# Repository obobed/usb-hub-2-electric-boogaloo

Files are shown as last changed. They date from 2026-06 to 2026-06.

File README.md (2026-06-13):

# UEB2
## another usb hub!
I made this since I wanted a unique USB hub with cool colours unlike some bland and boring ones you find off Amazon or places like that. It has 2 USB-C, 1 USB-A and an Micro SD card slot for downstream ports, and a USB-C female port for the upstream, alongside a cool 3D printed case with cool accent colours and an acrylic top window.

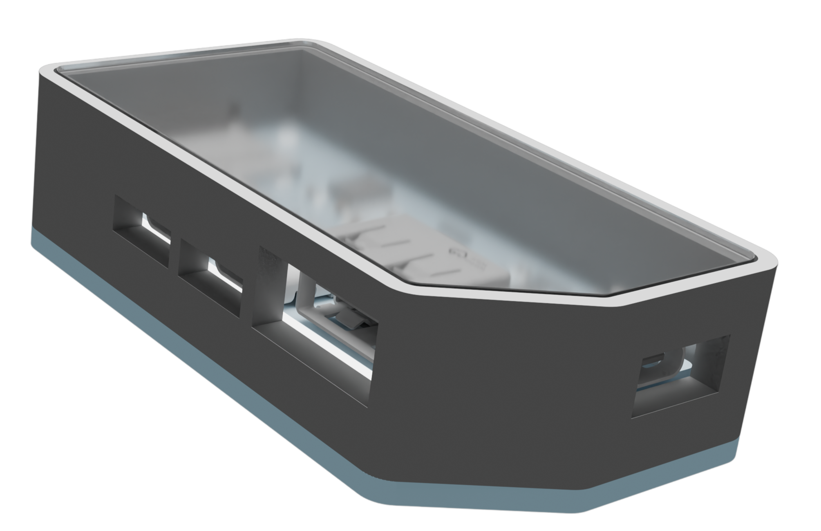
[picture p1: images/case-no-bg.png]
3d render of the case and pcb


## Repo Structure
When a directory includes a folder named "archive", that contains the files I used before I modified my PCB to use a female upstream port instead of a male one
* [/3D](/3D) - 3D models (both the components and the whole pcb exported as a STEP)
* [/cad](/cad) - my case exported from onshape (you can view the actual onshape link below), has both models with the PCB inside, and without the PCB
* [/images](/images) - various image assets used in my readme (here) and my zine!
* [/pcb](/pcb) - all of my kicad design files
* [/plots](/plots) - various plots, including dxfs for each layer, and a schematic image
* [/production](/production) - contains everything needed for PCB production, like gerbers and a component BOM
* [/rendering](/rendering) - the documents I used in Blender to render my design, with the OnShape exported objs in a subfolder
* [/zine](/zine) - my Zine! pdf and png included, and most assets are in [/images](/images)

## CAD
[OnShape link here!](https://cad.onshape.com/documents/3911889ee056a8d8e4ba98bf/w/b6e308ebfed3eeb37e65c26c/e/fc788076bb25bd97f4780c85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)
Step files can be found in [/cad](cad/)

## Images
### Schematic
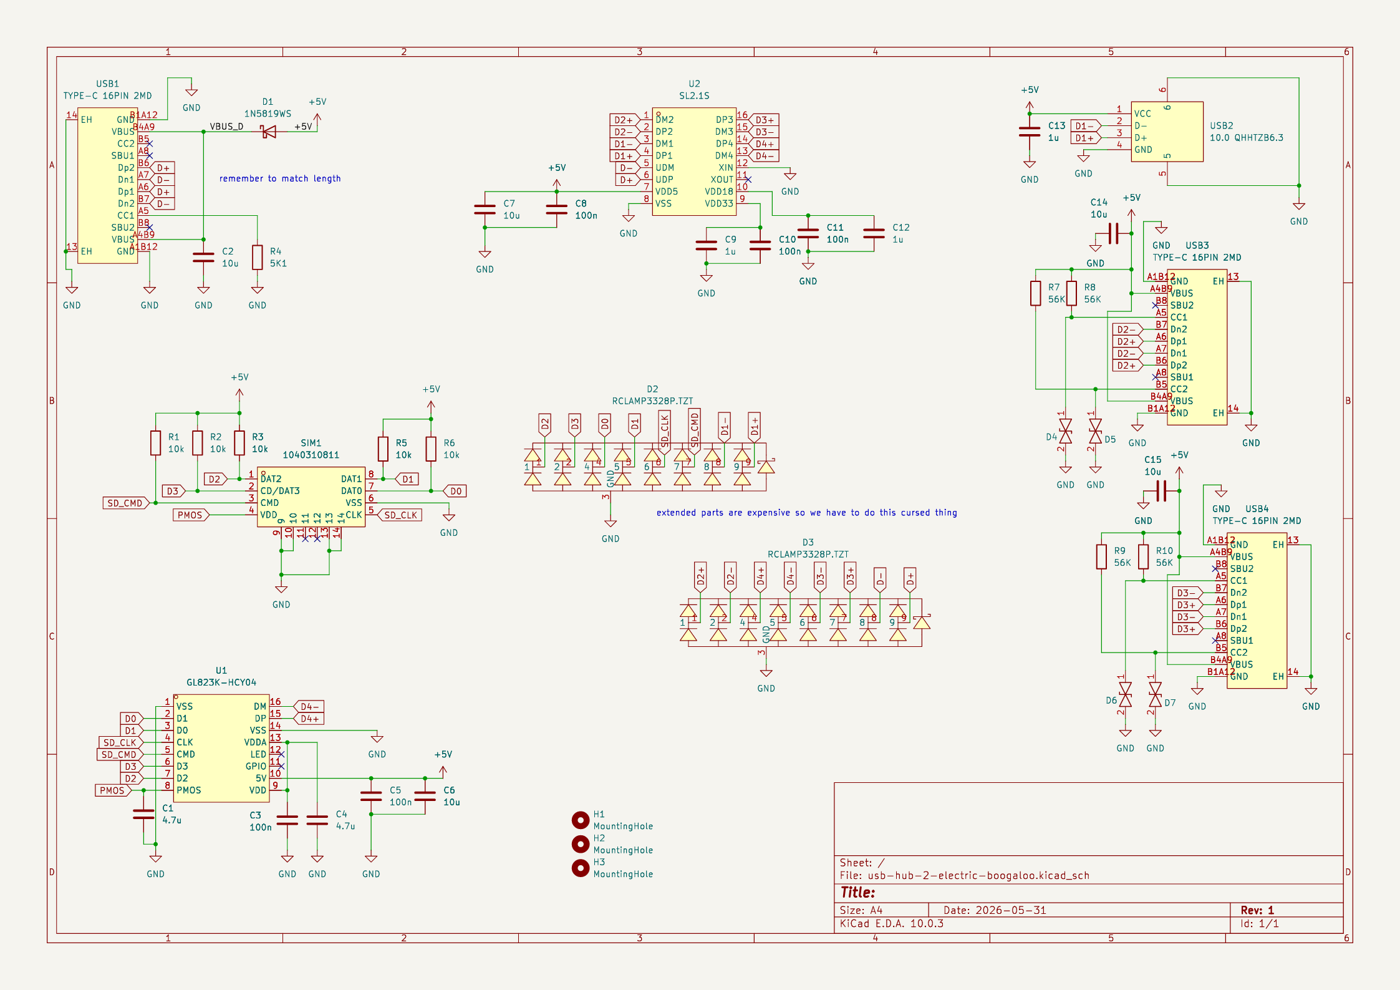
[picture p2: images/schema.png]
schematic


### 3D Model
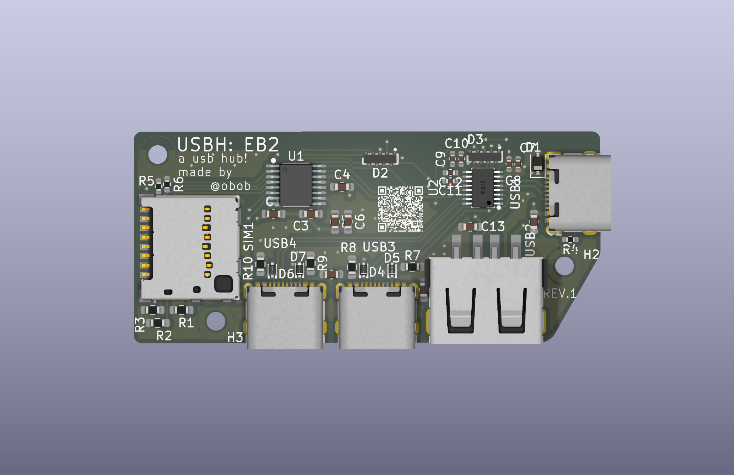
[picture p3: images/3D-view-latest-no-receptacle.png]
3D front view

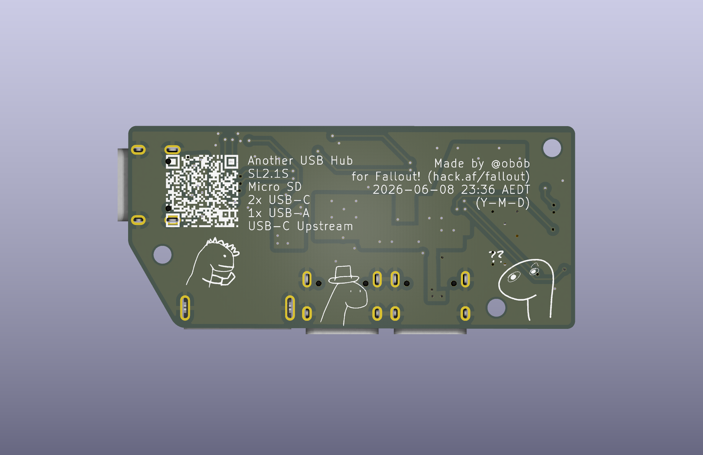
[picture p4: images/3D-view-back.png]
3D back view


### PCB
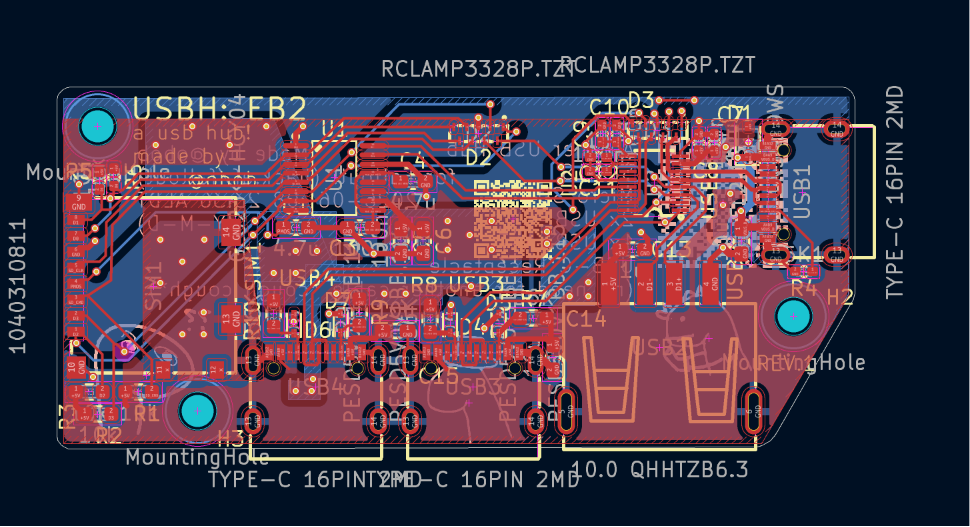
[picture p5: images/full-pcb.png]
full pcb image


#### Front Copper
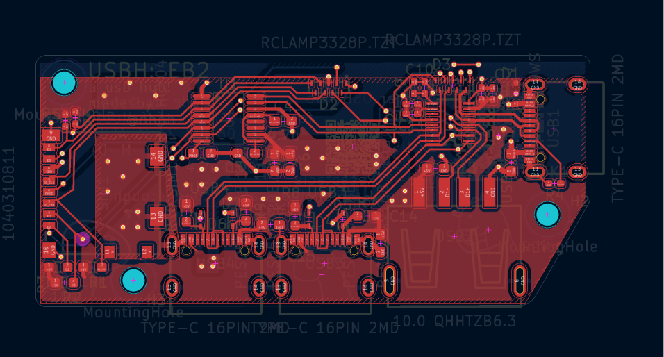
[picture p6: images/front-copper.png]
front copper pcb image


#### Back Copper
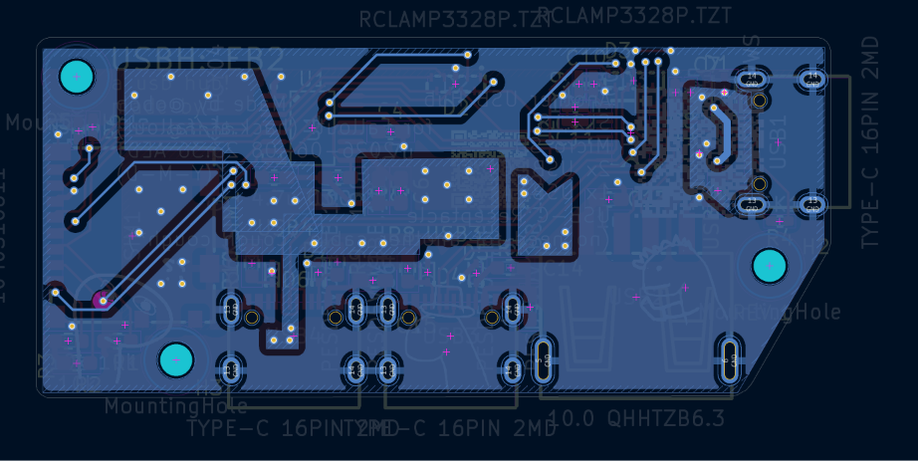
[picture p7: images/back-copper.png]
back copper pcb image


#### Silkscreen
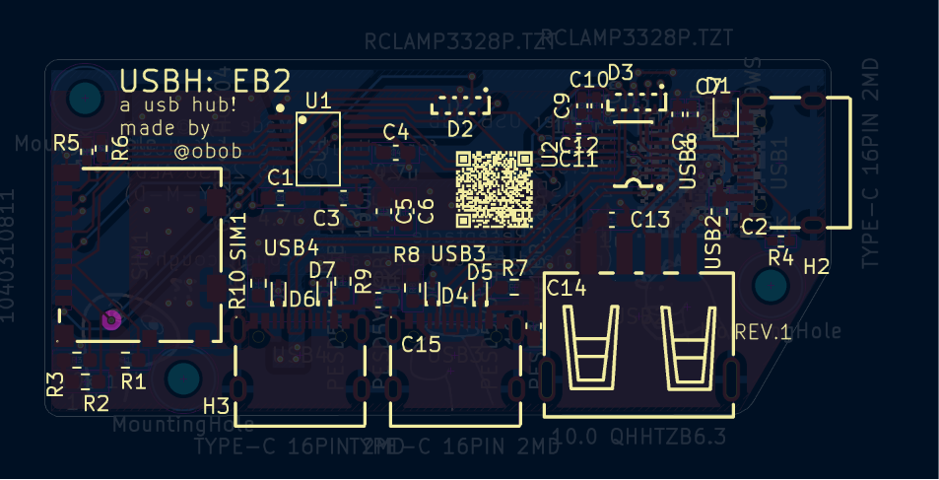
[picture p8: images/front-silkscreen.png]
front silkscreen image

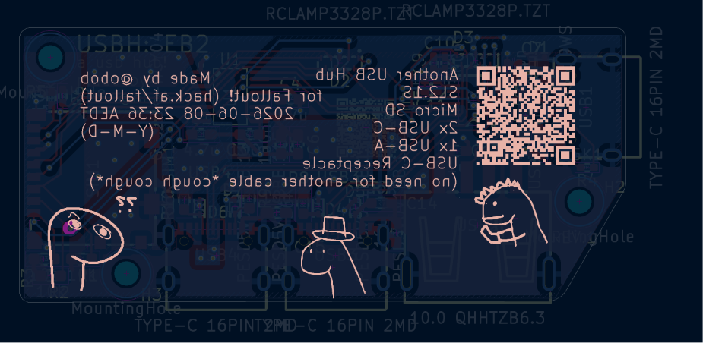
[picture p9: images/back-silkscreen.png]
back silkscreen image


## Assembly
### Top Acrylic Window
1. Print out the [top window template](/cad/acrylic-window-print-template.pdf) and stick it to your acrylic temporarily (using sticky tape or something like that)
2. Use a box cutter or acrylic cutter to score along the template
3. Snap along the score lines
4. Put a small amount of your adhesive (like Gorilla Gel) around the interior top lip
5. Place the acrylic ontop and wait a few minutes for it to set

> [!NOTE]
> I'm using glue here, since there aren't other good options that are fit in this size (like heatsets definitely won't) and wouldn't compromise the transparency of the acrylic

### PCB and Case
1. Get the heatset inserts and put them in the holes
2. Use a heated soldering iron to push them down until they're flush
3. Align the PCB with the holes
4. Screw the M2 screws in, and you're done!

## BOM
### OVERALL
|Item |Quantity |Link|Cost ($) USD unless said otherwise|Notes |
|---|---|----|---|---|
|Heatset inserts |3 |[aliexpress.com/item/1005006967339727](https://www.aliexpress.com/item/1005006967339727.html)|6.27 (AUD) |M2xL3xOD3.2 100pcs|
|Screws |50 |[aliexpress.com/item/32969042589](https://www.aliexpress.com/item/32969042589.html)|1.69 (AUD) |M2, Length 4mm, 50pcs is the MOQ, since obv you can't order individual screws|
|3D Printed Case |1 | |FREE (if you have a printer, which I do)| |
|PCB |5 |[jlcpcb.com](https://jlcpcb.com)|4.00 | |
|PCBA |2 |[jlcpcb.com](https://jlcpcb.com)|47.54 | |
|PCB Shipping |1 |[jlcpcb.com](https://jlcpcb.com)|1.50 | |
|Acrylic |1 |[aliexpress.com/item/32817321651.html](https://www.aliexpress.com/item/32817321651.html)|2.99 (AUD) |100x100x2. If you need, get an acrylic cutter. I don't have one in this BOM as I have a box cutter and that works fine with this 2mm sheet. Additionally, if you don't already have an adhesive (like [Gorilla Super Glue Gel](https://www.bunnings.com.au/gorilla-20g-super-glue-gel_p0381626), you will have to get it, but it's not included here as I already have it|
| | | | | |
|TOTAL | | |53.04 USD + 10.95 AUD | |

### PCB Components
> [!IMPORTANT]
> **This is already included under 'PCBA' in the overall BOM, these are just the indivdual component costs, don't double count it**

|Designator |Footprint |Quantity|Value |LCSC Part #|Link |Cost ($)|
|---|---|---|---|---|---|---|
|C1, C4 |603 |2 |4.7u |C19666 |https://jlcpcb.com/partdetail/20375-CL10A475KO8NNNC/C19666 |0.184 |
|C10, C11, C8 |402 |3 |100n |C1525 |https://jlcpcb.com/partdetail/1877-CL05B104KO5NNNC/C1525 |0.0345  |
|C12, C9 |402 |2 |1u |C52923 |https://jlcpcb.com/partdetail/53938-CL05A105KA5NQNC/C52923 |0.069 |
|C13 |603 |1 |1u |C15849 |https://jlcpcb.com/partdetail/16531-CL10A105KB8NNNC/C15849 |0.079 |
|C14, C15, C2, C6|603 |4 |10u |C19702 |https://jlcpcb.com/partdetail/20411-CL10A106KP8NNNC/C19702 |0.346 |
|C3, C5 |603 |2 |100n |C14663 |https://jlcpcb.com/partdetail/YAGEO-CC0603KRX7R9BB104/C14663 |0.094 |
|C7 |402 |1 |10u |C15525 |https://jlcpcb.com/partdetail/16204-CL05A106MQ5NUNC/C15525 |0.093 |
|D1 |D_SOD-323 |1 |1N5819WS |C191023 |https://jlcpcb.com/partdetail/GuangdongHottech-1N5819WS/C191023 |0.0555  |
|D2, D3 |UDFN-9_L3.9-W1.1-P0.80-BL |2 |RCLAMP3328P.TZT |C3040834 |https://jlcpcb.com/partdetail/SEMTECH-RCLAMP3328PTZT/C3040834 |8.191 |
|D4, D5, D6, D7  |SOD-523_L1.2-W0.8-LS1.6-RD |4 |PESD5V0V1BB,115 |C477993 |https://jlcpcb.com/partdetail/Nexperia-PESD5V0V1BB115/C477993 |8.6925  |
|R1, R2, R3 |603 |3 |10k |C25804 |https://jlcpcb.com/partdetail/26547-0603WAF1002T5E/C25804 |0.021 |
|R10, R7, R8, R9 |603 |4 |56K |C23206 |https://jlcpcb.com/partdetail/23933-0603WAF5602T5E/C23206 |0.04 |
|R4 |402 |1 |5K1 |C25905 |https://jlcpcb.com/partdetail/26648-0402WGF5101TCE/C25905 |0.0045  |
|R5, R6 |402 |2 |10k |C25744 |https://jlcpcb.com/partdetail/26487-0402WGF1002TCE/C25744 |0.028 |
|SIM1 |SIM-SMD_8P-1040310811 |1 |1040310811 |C585350 |https://jlcpcb.com/partdetail/MOLEX-1040310811/C585350 |3.37 |
|U1 |SSOP-16_L4.9-W3.9-P0.64-LS6.0-BL|1 |GL823K-HCY04 |C284879 |https://jlcpcb.com/partdetail/GenesysLogic-GL823KHCY04/C284879 |2.2815  |
|U2 |SSOP-16_L4.6-W2.6-P0.53-LS4.0-BL|1 |SL2.1S |C2684433 |https://jlcpcb.com/partdetail/CoreChips-SL21s/C2684433 |1.253 |
|USB1, USB3, USB4|USB-C-SMD_TYPE-C-16PIN-2MD-073  |3 |TYPE-C 16PIN 2MD|C2765186 |https://jlcpcb.com/partdetail/SHOUHAN-TYPE_C_16PIN_2MD_073/C2765186|1.1776  |
|USB2 |USB-A-TH_10.0QHHTZB6.3 |1 |10.0 QHHTZB6.3  |C668591 |https://jlcpcb.com/partdetail/SHOUHAN-10_0_QHHTZB63/C668591 |0.4634  |
| | | | | | | |
|TOTAL | | | | | |26.4775 |

## Zine!!
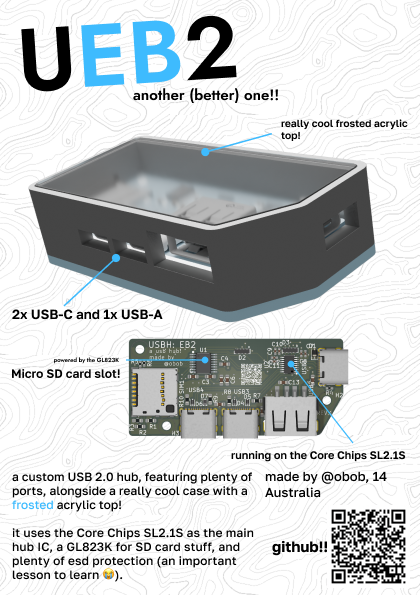
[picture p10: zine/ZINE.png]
zine page


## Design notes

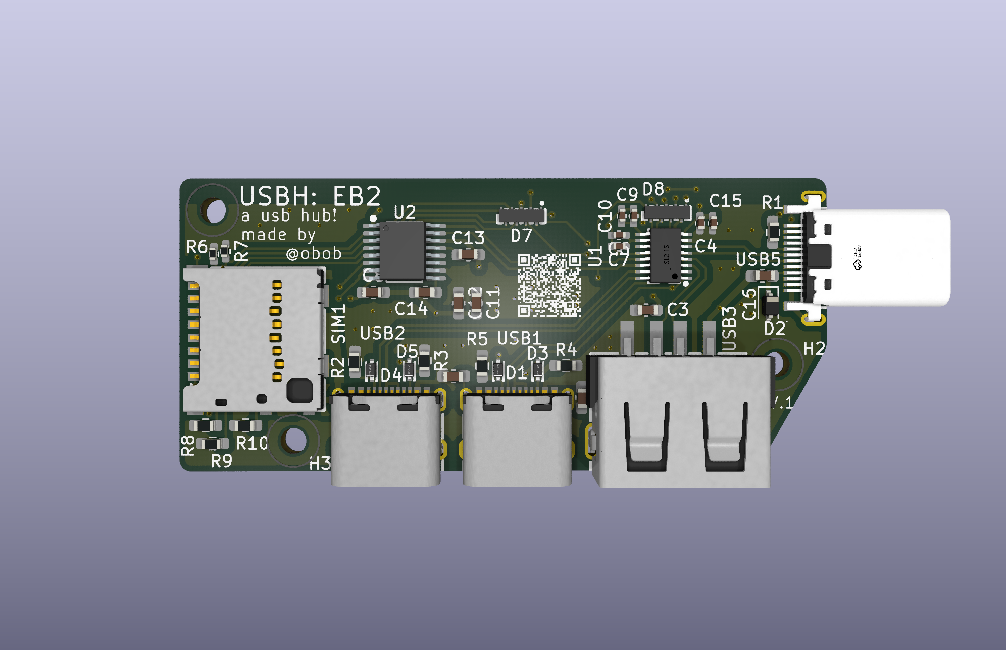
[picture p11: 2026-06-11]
images/3D-view.png

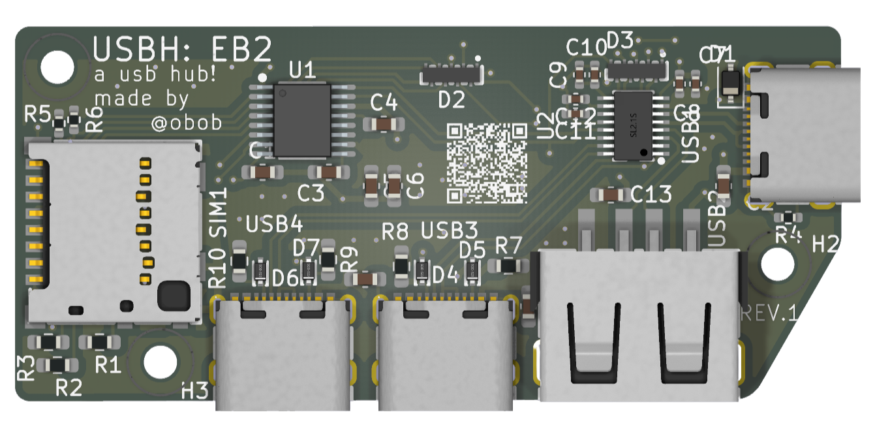
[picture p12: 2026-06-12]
images/pcb-no-bg.png

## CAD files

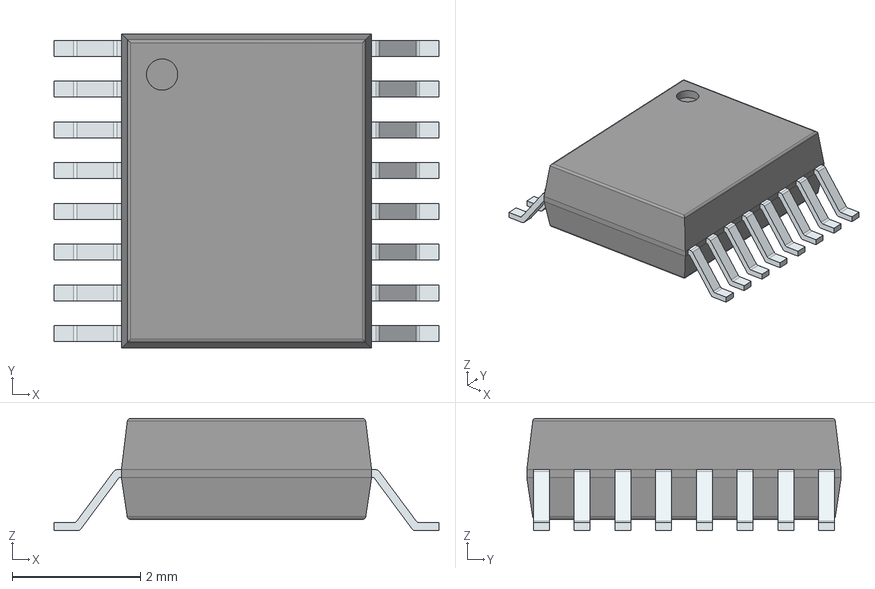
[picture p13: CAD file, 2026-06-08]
3D/GL823K.stp
6.00 x 4.90 x 1.75 mm
PinsArrayLR

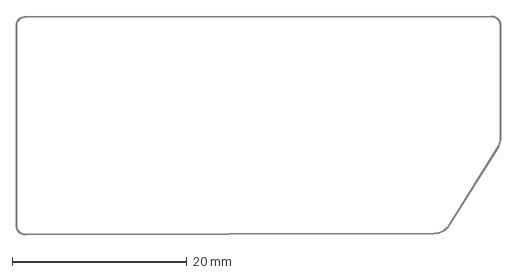
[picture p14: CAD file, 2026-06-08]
plots/usb-hub-2-electric-boogaloo-Edge_Cuts.dxf
55.5 x 25.0 mm

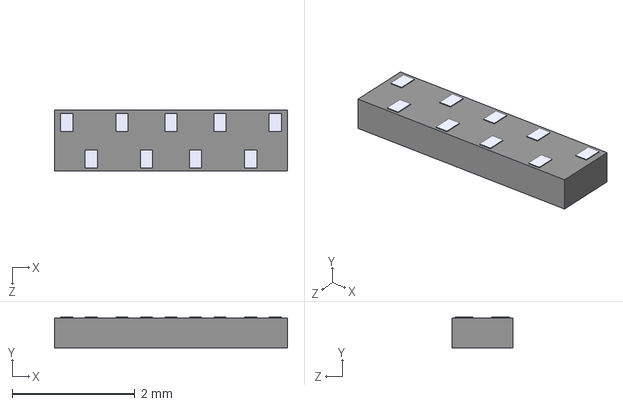
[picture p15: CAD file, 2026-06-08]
3D/RCLAMP3328P.TZT.stp
3.80 x 0.5 x 1 mm

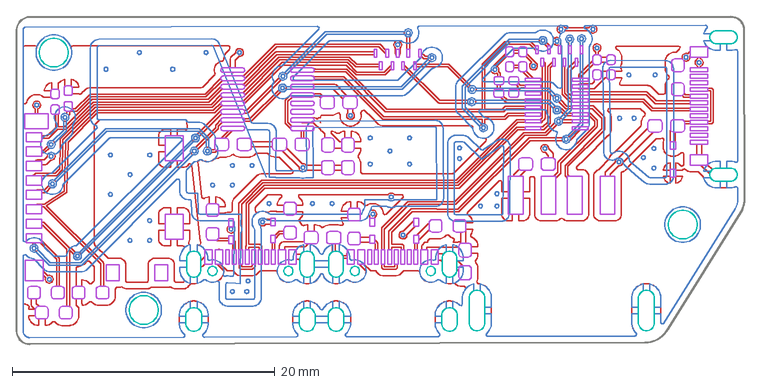
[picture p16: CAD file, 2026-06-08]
plots/usb-hub-2-electric-boogaloo.dxf
55.5 x 25.0 mm

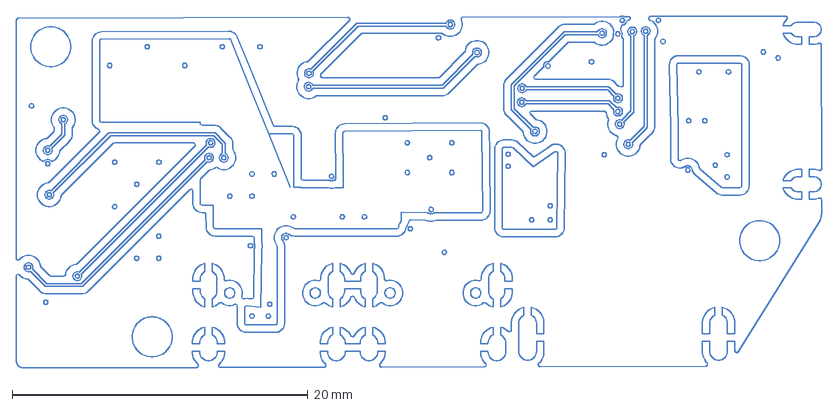
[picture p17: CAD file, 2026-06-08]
plots/usb-hub-2-electric-boogaloo-B_Cu.dxf
54.4 x 23.8 mm

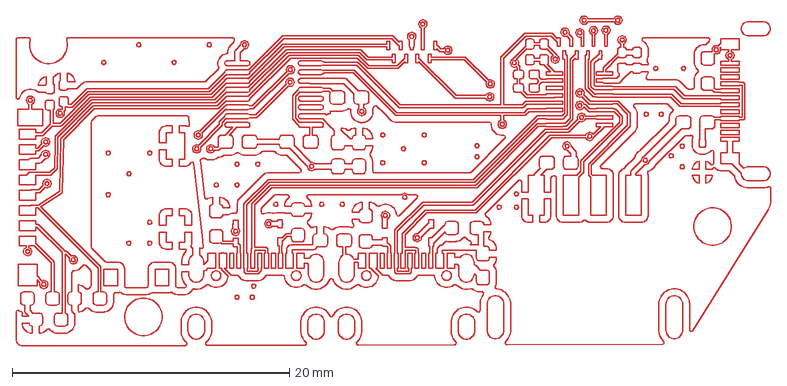
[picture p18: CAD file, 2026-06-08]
plots/usb-hub-2-electric-boogaloo-F_Cu.dxf
54.4 x 23.8 mm

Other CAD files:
plots/usb-hub-2-electric-boogaloo-B_Mask.dxf
plots/usb-hub-2-electric-boogaloo-B_Paste.dxf
plots/usb-hub-2-electric-boogaloo-B_Silkscreen.dxf
plots/usb-hub-2-electric-boogaloo-F_Mask.dxf
plots/usb-hub-2-electric-boogaloo-F_Paste.dxf

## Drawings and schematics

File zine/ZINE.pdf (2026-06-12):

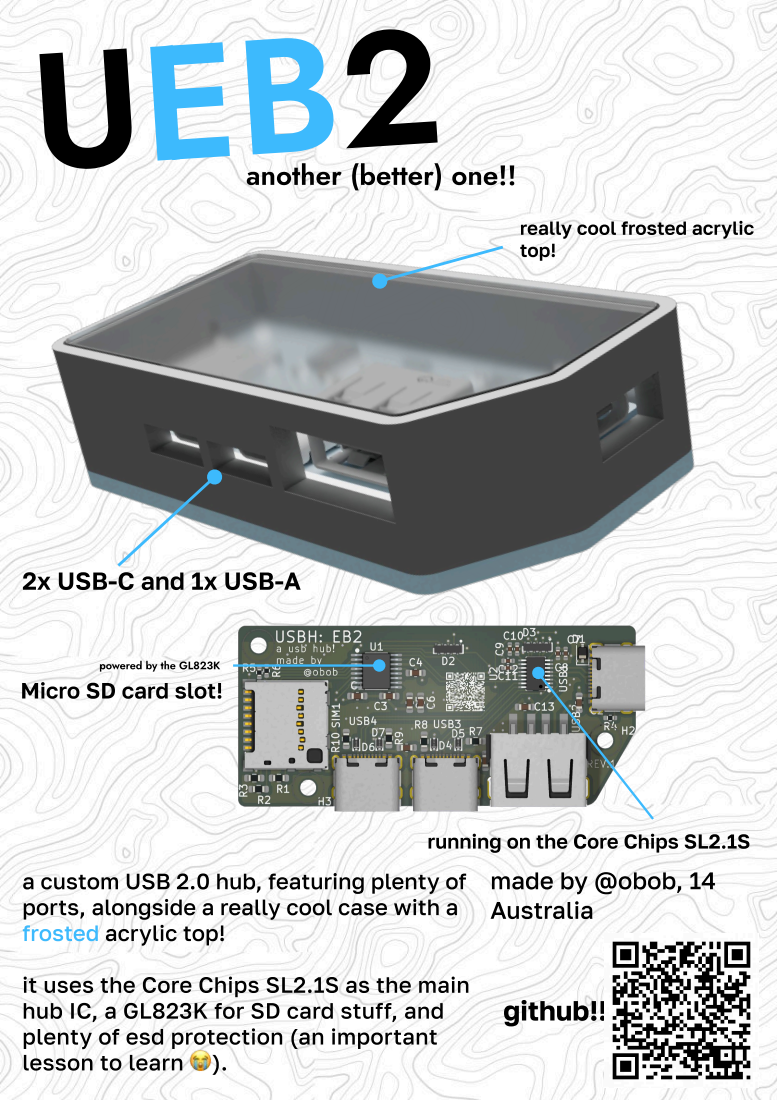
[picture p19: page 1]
UEB2another (better) one!!; github!!

really cool frosted acrylic
top!

2x USB-C and 1x USB-A

powered by the GL823K

Micro SD card slot!

running on the Core Chips SL2.1S
made by @obob, 14
Australia

a custom USB 2.0 hub, featuring plenty of
ports, alongside a really cool case with a
frosted acrylic top!

it uses the Core Chips SL2.1S as the main
hub IC, a GL823K for SD card stuff, and
plenty of esd protection (an important
lesson to learn 😭).

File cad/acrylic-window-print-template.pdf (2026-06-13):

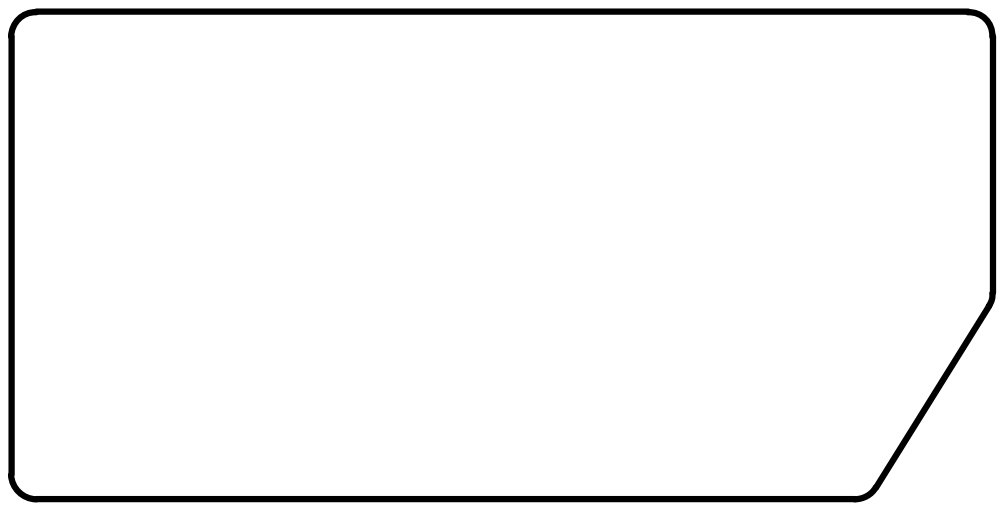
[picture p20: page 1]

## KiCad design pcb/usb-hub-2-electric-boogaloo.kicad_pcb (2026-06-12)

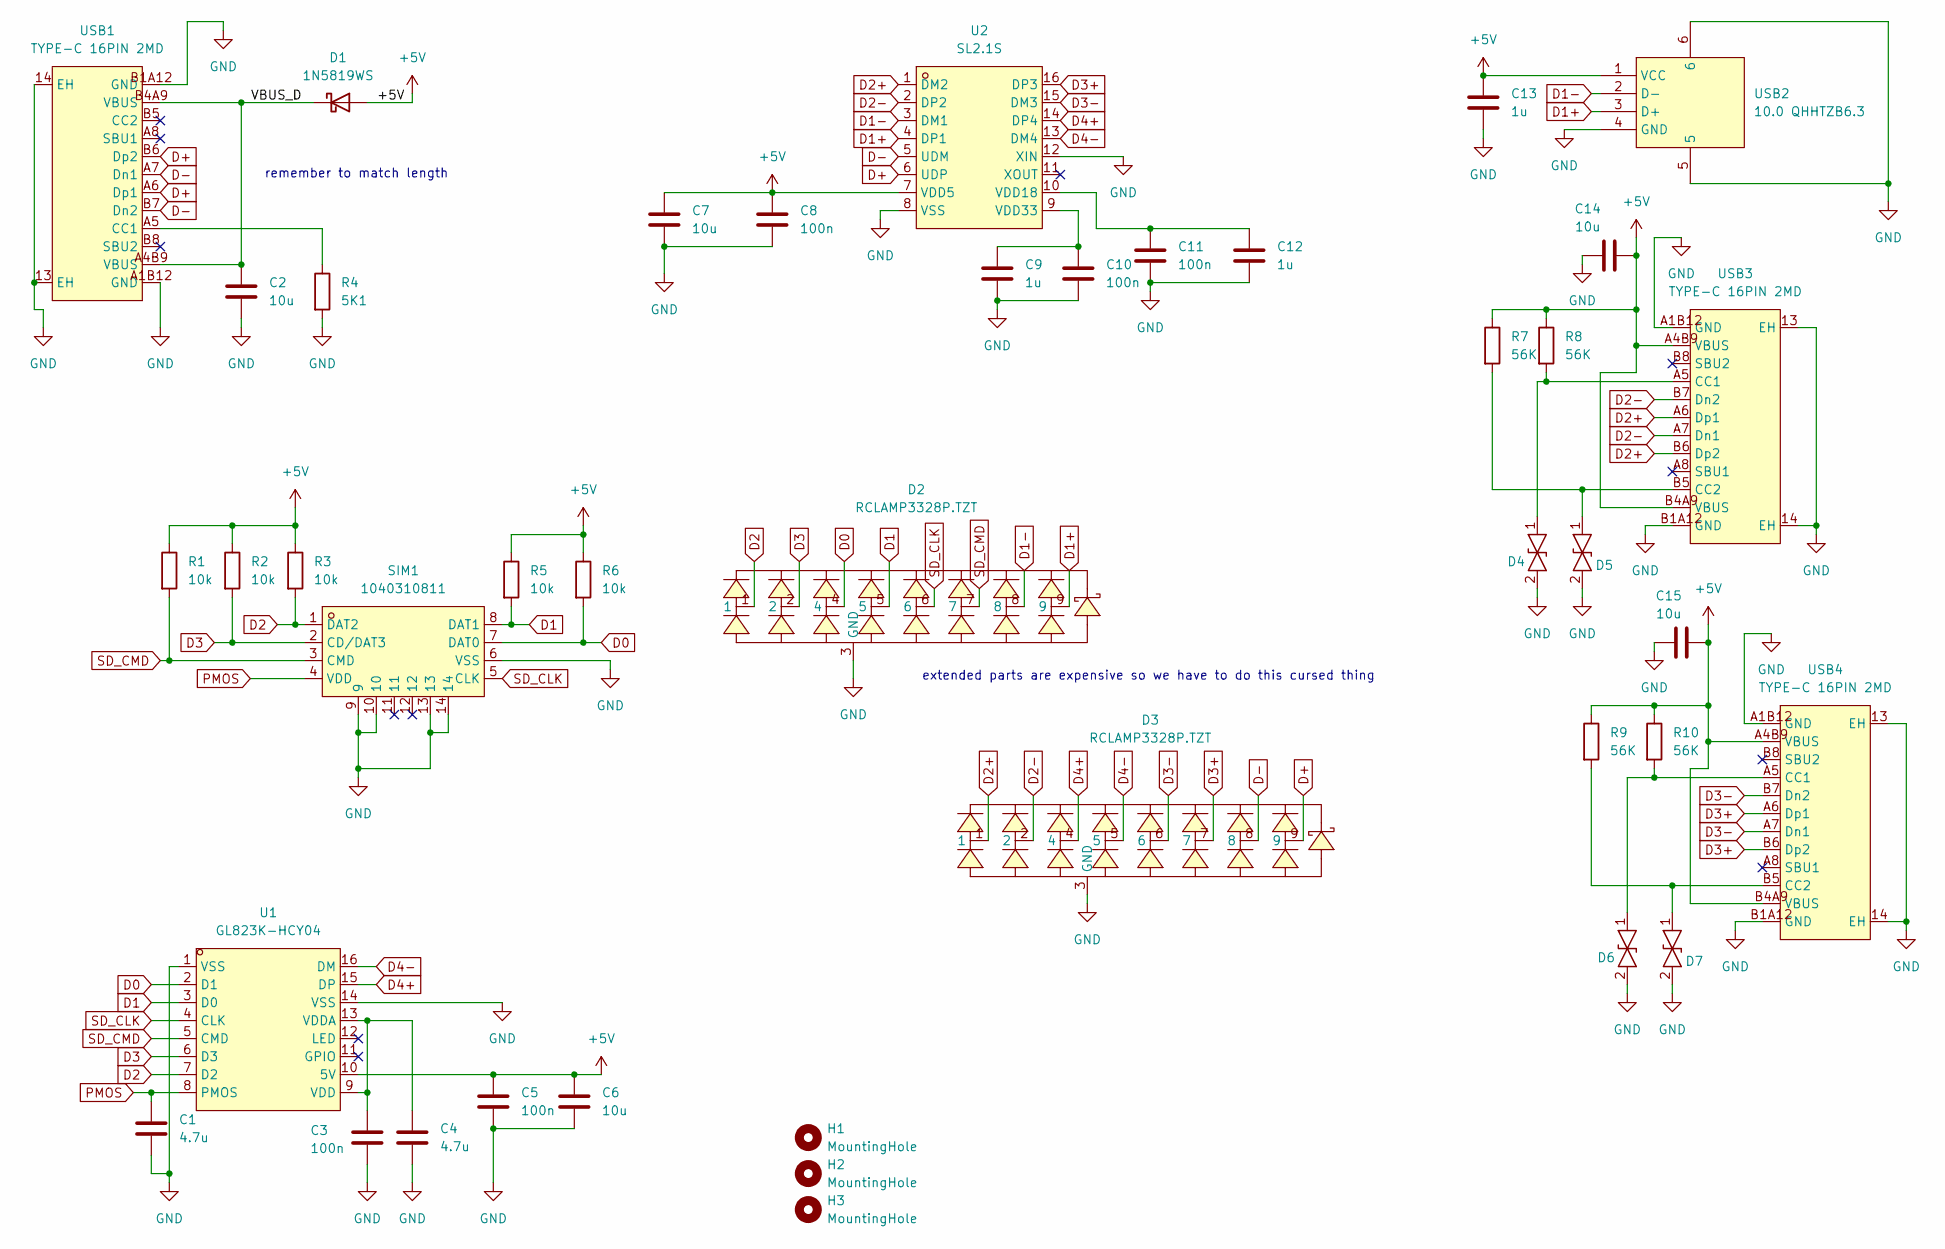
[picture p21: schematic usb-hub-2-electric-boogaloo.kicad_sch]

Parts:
C1, C4: 4.7u; C_0603_1608Metric_Pad1.08x0.95mm_HandSolder
C2, C6, C14, C15: 10u; C_0603_1608Metric_Pad1.08x0.95mm_HandSolder
C3, C5: 100n; C_0603_1608Metric_Pad1.08x0.95mm_HandSolder
C7: 10u; C_0402_1005Metric_Pad0.74x0.62mm_HandSolder
C8, C10, C11: 100n; C_0402_1005Metric_Pad0.74x0.62mm_HandSolder
C9, C12: 1u; C_0402_1005Metric_Pad0.74x0.62mm_HandSolder
C13: 1u; C_0603_1608Metric_Pad1.08x0.95mm_HandSolder
D1: 1N5819WS; D_SOD-323
D2, D3: RCLAMP3328P.TZT; UDFN-9_L3.9-W1.1-P0.80-BL; MPN RCLAMP3328P.TZT; LCSC Part C3040834
D4, D5, D6, D7: PESD5V0V1BB,115; SOD-523_L1.2-W0.8-LS1.6-RD; MPN PESD5V0V1BB,115; LCSC Part C477993
H1, H2, H3: MountingHole; MountingHole_2.2mm_M2
R1, R2, R3: 10k; R_0603_1608Metric_Pad0.98x0.95mm_HandSolder
R4: 5K1; R_0402_1005Metric_Pad0.72x0.64mm_HandSolder
R5, R6: 10k; R_0402_1005Metric_Pad0.72x0.64mm_HandSolder
R7, R8, R9, R10: 56K; R_0603_1608Metric_Pad0.98x0.95mm_HandSolder
SIM1: 1040310811; SIM-SMD_8P-1040310811; MPN 1040310811; LCSC Part C585350
U1: GL823K-HCY04; SSOP-16_L4.9-W3.9-P0.64-LS6.0-BL; LCSC Part C284879
U2: SL2.1S; SSOP-16_L4.6-W2.6-P0.53-LS4.0-BL; MPN SL2.1s; LCSC Part C2684433
USB1, USB3, USB4: TYPE-C 16PIN 2MD; USB-C-SMD_TYPE-C-16PIN-2MD-073; MPN TYPE-C 16PIN 2MD(073); LCSC Part C2765186
USB2: 10.0 QHHTZB6.3; USB-A-TH_10.0QHHTZB6.3; MPN 10.0 QHHTZB6.3; LCSC Part C668591

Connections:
+5V: C5.1, C6.1, C7.1, C8.1, C13.1, C14.1, C15.2, D1.2 (A), R1.1, R2.1, R3.1, R5.1, R6.1, R7.1, R8.1, R9.1, R10.1, U1.10 (5V), U2.7 (VDD5), USB2.1 (VCC), USB3.A4B9 (VBUS), USB3.B4A9 (VBUS), USB4.A4B9 (VBUS), USB4.B4A9 (VBUS)
/VBUS_D: C2.1, D1.1 (K), USB1.A4B9 (VBUS), USB1.B4A9 (VBUS)
D0: D2.4, R6.2, SIM1.7 (DAT0), U1.2 (D1)
D1: D2.5, R5.2, SIM1.8 (DAT1), U1.3 (D0)
D1+: D2.9, U2.4 (DP1), USB2.3 (D+)
D1-: D2.8, U2.3 (DM1), USB2.2 (D-)
D2: D2.1, R3.2, SIM1.1 (DAT2), U1.7 (D2)
D2+: D3.1, U2.1 (DM2), USB3.A6 (Dp1), USB3.B6 (Dp2)
D2-: D3.2, U2.2 (DP2), USB3.A7 (Dn1), USB3.B7 (Dn2)
D3: D2.2, R2.2, SIM1.2 (CD/DAT3), U1.6 (D3)
D3+: D3.7, U2.16 (DP3), USB4.A6 (Dp1), USB4.B6 (Dp2)
D3-: D3.6, U2.15 (DM3), USB4.A7 (Dn1), USB4.B7 (Dn2)
D4+: D3.4, U1.15 (DP), U2.14 (DP4)
D4-: D3.5, U1.16 (DM), U2.13 (DM4)
D+: D3.9, U2.6 (UDP), USB1.A6 (Dp1), USB1.B6 (Dp2)
D-: D3.8, U2.5 (UDM), USB1.A7 (Dn1), USB1.B7 (Dn2)
GND: C1.2, C2.2, C3.1, C4.2, C5.2, C6.2, C7.2, C8.2, C9.2, C10.2, C11.2, C12.2, C13.2, C14.2, C15.1, D2.3 (GND), D3.3 (GND), D4.2, D5.2, D6.2, D7.2, R4.2, SIM1.6 (VSS), SIM1.9, SIM1.10, SIM1.13, SIM1.14, U1.1 (VSS), U1.14 (VSS), U2.8 (VSS), U2.12 (XIN), USB1.13 (EH), USB1.14 (EH), USB1.A1B12 (GND), USB1.B1A12 (GND), USB2.4 (GND), USB2.5, USB2.6, USB3.13 (EH), USB3.14 (EH), USB3.A1B12 (GND), USB3.B1A12 (GND), USB4.13 (EH), USB4.14 (EH), USB4.A1B12 (GND), USB4.B1A12 (GND)
unnamed: C3.2, C4.1, U1.9 (VDD), U1.13 (VDDA)
unnamed: C11.1, C12.1, U2.10 (VDD18)
unnamed: C9.1, C10.1, U2.9 (VDD33)
unnamed: R4.1, USB1.A5 (CC1)
unnamed: D4.1, R8.2, USB3.A5 (CC1)
unnamed: D5.1, R7.2, USB3.B5 (CC2)
unnamed: D6.1, R10.2, USB4.A5 (CC1)
unnamed: D7.1, R9.2, USB4.B5 (CC2)
PMOS: C1.1, SIM1.4 (VDD), U1.8 (PMOS)
SD_CLK: D2.6, SIM1.5 (CLK), U1.4 (CLK)
SD_CMD: D2.7, R1.2, SIM1.3 (CMD), U1.5 (CMD)

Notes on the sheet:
extended parts are expensive so we have to do this cursed thing
remember to match length

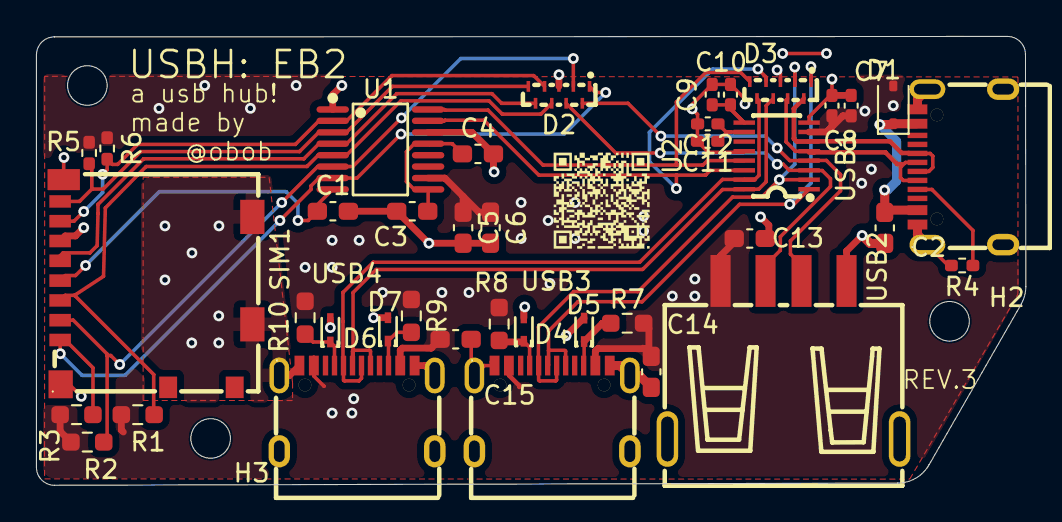
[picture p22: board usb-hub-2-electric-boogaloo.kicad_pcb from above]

Board: 2 copper layers, 55.0 x 24.9 mm, 42 parts (0 on the bottom side), 28 nets.

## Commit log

2026-05-27 schema except for sd bc that takes time
    [usb-hub-2-electric-boogaloo.kicad_pcb, usb-hub-2-electric-boogaloo.kicad_sch]
2026-05-27 probably messed something up, but schema done!
    [usb-hub-2-electric-boogaloo.kicad_sch]
2026-05-30 fixing schema + lots of esd protection
    [usb-hub-2-electric-boogaloo.kicad_sch]
2026-05-30 fixed some stuff
    schottky + more decoupling caps
    [usb-hub-2-electric-boogaloo.kicad_sch]
2026-06-01 pcb layout + revise usb-c schema
    [usb-hub-2-electric-boogaloo.kicad_pcb, usb-hub-2-electric-boogaloo.kicad_sch]
2026-06-01 some (bad) routing
    [usb-hub-2-electric-boogaloo.kicad_pcb]
2026-06-02 routing traces
    [usb-hub-2-electric-boogaloo.kicad_pcb, usb-hub-2-electric-boogaloo.kicad_sch]
2026-06-05 finish main routing (still disconnects tho)
    [usb-hub-2-electric-boogaloo.kicad_pcb, usb-hub-2-electric-boogaloo.kicad_sch]
2026-06-06 vias and mounting holes
    [usb-hub-2-electric-boogaloo.kicad_pcb, usb-hub-2-electric-boogaloo.kicad_sch]
2026-06-06 whoops drc exists
    [usb-hub-2-electric-boogaloo.kicad_pcb]
2026-06-08 dxf + fixed 3D view + silkscreen
    [GL823K.stp, RCLAMP3328P.TZT.stp, usb-hub-2-electric-boogaloo-B_Cu.dxf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]
2026-06-11 zine + cad case + renders
    [usb-hub-2-electric-boogaloo.kicad_pcb]
2026-06-12 fix usb + new renders
    [usb-hub-2-electric-boogaloo.kicad_pcb, usb-hub-2-electric-boogaloo.kicad_sch]
2026-06-12 basic readme, need more intro and conclusion and glue/adhesive for acrylic (also aliexpress)
2026-06-12 restructure folders
    get rid of the unnecessary nested folder
    [GL823K.stp, RCLAMP3328P.TZT.stp, usb-hub-2-electric-boogaloo-B_Cu.dxf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]
2026-06-12 rename 3d folder so i can link in readme
    [GL823K.stp, RCLAMP3328P.TZT.stp]
2026-06-12 add pcb and schema images
2026-06-12 update rev and add 3D back image
    [usb-hub-2-electric-boogaloo.kicad_pcb]
2026-06-12 improve readme with CAD, images, and BOM sections
2026-06-13 update bom, add more images and assembly steps
2026-06-13 add case assembly instructions
